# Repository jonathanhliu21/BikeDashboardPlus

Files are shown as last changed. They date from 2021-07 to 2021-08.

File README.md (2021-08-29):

# BikeDashboardPlus

### Go to the [Medium page](https://medium.com/@jonathanhliu21/how-to-make-a-speedometer-tracker-for-a-bike-using-a-raspberry-pi-and-an-arduino-77140be90b9e) for a better installation tutorial! 

- [How to use your Bike Dashboard](docs/pages/usage.md)

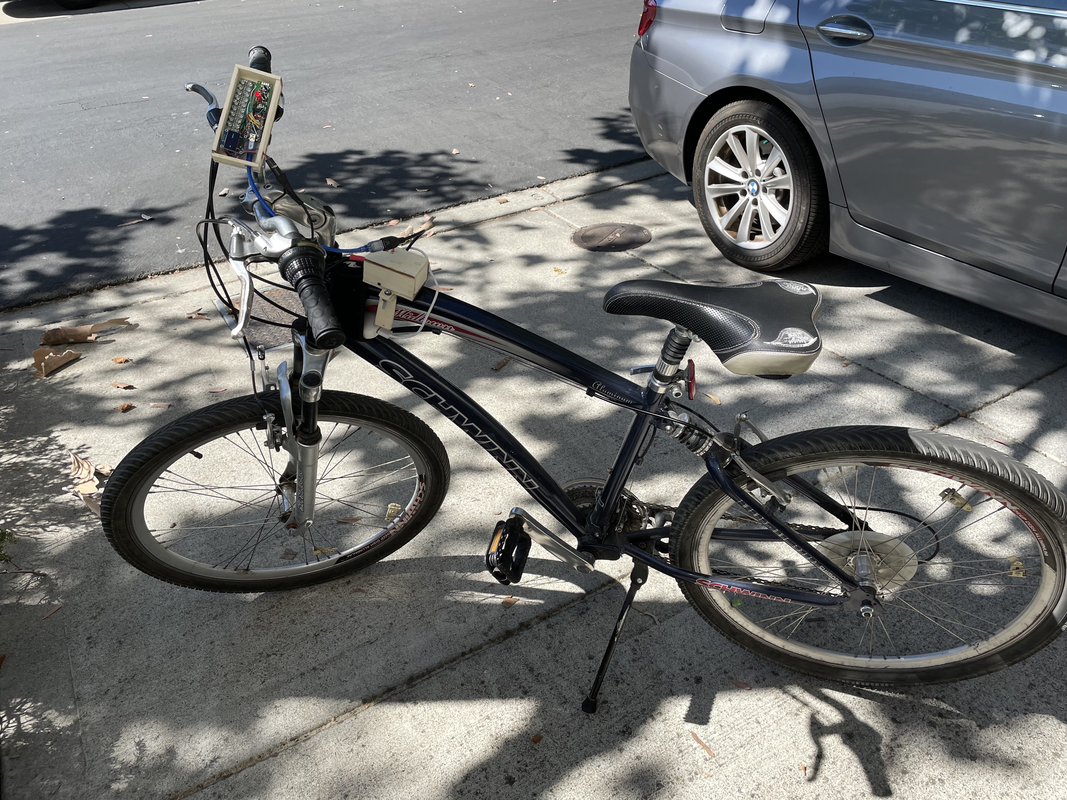
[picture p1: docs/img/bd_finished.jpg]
BD_finished
  

## Description

Over my spring break in April 2021, I made a "Bike Dashboard" ([Project description](https://create.arduino.cc/projecthub/jonathanhliu21/a-dashboard-for-a-bike-unfinished-6dc0cb), [Github Repo](https://github.com/jonyboi396825/BikeDashboard)) using an Arduino Nano, an LCD screen, and a GPS. I made this to make finding out the time while riding a bike safer, and I wanted a safe way to track the route that I biked. I thought that pulling over my bike to check my phone for the time was inconvenient, and checking my phone while biking was dangerous. I was also interested in viewing the speed while biking.

However, That design had many problems. I could not put that many features on it because the Nano did not have much memory. The speed on the LCD updated very slowly. The LCD screen was also very big and captured attention, which may have gotten my bike stolen. Lastly, even though it could track, I had no way of viewing it on a map. Because of these problems, I wanted a new design.

<figure>
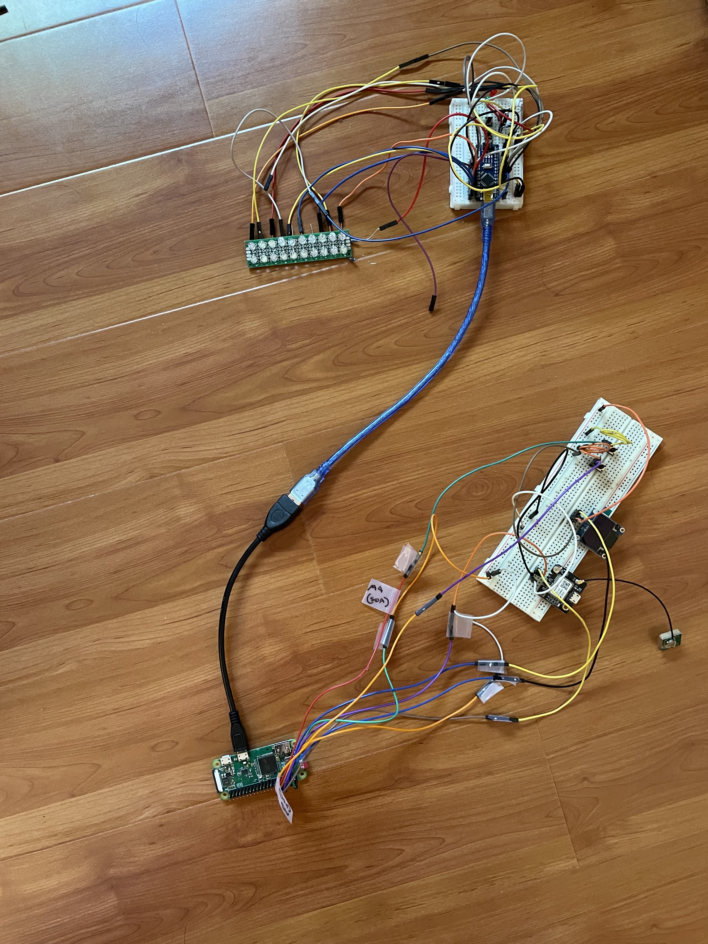
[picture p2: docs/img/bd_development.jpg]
    
    <figcaption>BikeDashboardPlus in development. The breadboard and Raspberry Pi on the bottom would be the central piece, and the breadboard on the top would be the handle piece.</figcaption>
</figure>

## How it works

This new Bike Dashboard features a Raspberry Pi that gets the data from the GPS and puts it onto an OLED. It is connected to the Arduino via USB, and the Arduino controls the buttons for route tracking (start/stop/pause tracking), and a 2x20 LED panel that can currently only display speed by lighting up a certain LED that corresponds to a number.

The OLED displays speed, date and time, how well the GPS is connected (No fix, 2D fix, or 3D fix), and the state of tracking (tracking, paused, or not tracking). 

Additionally, there is another mode called "server mode," where the Raspberry Pi runs a local website. On the website, the user can customize units, time zone, and other features. They can also view their tracked routes on a map. Lastly, if the GPS disconnected or stopped tracking while biking and the user had to restart the tracking, they can combine those two track files into one.

With the Raspberry Pi, I solved the low memory problem and the slowness issue. I was able to get the GPS data in a separate thread so it wouldn't block the program. I tried to make it inconspicuous by using a small OLED and LED panel, but my design still makes the bike capture a lot of attention.

To get a more in-depth understanding of how it works, go [here](docs/pages/usage.md).

## Problems I ran into 

These are some major problems I ran into while working on this project.

| Problem | How I solved it |
|---|---|
| The LED matrix couldn't light up 2 LEDs at once because I wired the circuit wrong. I originally wanted *n* LEDs to light up if I was going at speed *n*. | Instead of resoldering the entire LED matrix, which would have taken a long time, I changed the feature so that only one LED would light up at a time, and that LED would correspond to a certain speed. |
| The light on the LED matrix would be very dim when it lit up. | This was caused by my code not checking if any LEDs in that row were being used, therefore lighting up 2 LEDs back and forth in quick succession, making the LED seem dim. I added an `if` statement that would check if any LEDs were on in that row and turn them off before turning the current one on. |
OSError on OLED: Because I was writing data to the OLED too quickly, after a few minutes, the program would raise an OSError and stop because the data would not be written successfully to the OLED. | I tried experimenting with the amount of delay between writing data to the OLED and seeing how long it would last before raising an OSError. However, I realized I can catch the error and let the user re-begin the OLED, which was a much more reliable solution. |
| The GPS on the bike would take 5 minutes to connect, which was too slow. | I glued the antenna position of the GPS to the top of the central piece instead of the side, so it is pointed directly to the sky. It now takes 1 minute to connect.

Other problems:
- I accidentally soldered the purple LEDs with the white ones on the LED panel because they looked similar (they were both clear).
- For the case, I bought wood too hard to be cut by a knife, so I had to use a saw instead, and it did not cut the wood perfectly. This made it very hard to assemble the case and glue everything together. Thanks to my dad for helping me cut the wood and designing the case and mount.

## Problems that still occur

The bugs are listed below. I will try my best to fix most of them, delete them from this list, and create a new bug-fixing release each time I do so. However, some may take longer than others to fix.

- The shutdown button can be easily pressed so I sometimes accidentally shut down my RPi even when I don't mean to.
- The OLED library I'm using (Adafruit-SSD1306) is deprecated.

### Done
- The track files are in UTC rather than the local time zone

## Upgrade ideas

I will try to implement these enhancements as long as they are not a major change (e.g. a complete rewrite in code, a complete redesign of the mounts and case, needing different parts, or a change in the schematics), or they are not too time-consuming to implement, as I have a very busy schedule. I may not have time to implement all of them. They will be released as features in a minor release.

### Next minor release
- Allow users to separate tracking files after combining them
- If the user chooses to update from the website, then automatically pull from the repository

### Later minor releases
- Track the distance along with coordinates instead of calculating the distance after
- Make the LED panel show more than just speed
- Make a more intuitive configuration page
- Put the Pi in "sleep" mode or alter the OS such that it will boot faster (takes ~2min currently)
- Track speed and time in addition to distance and location

### Next major release
- Remake BOM to include smaller parts and redesign model so everything will be in one small piece attached to the bike

### Done 
- Continue tracking even if disconnected

## Making this project yourself

If you have a Raspberry Pi and a bike, and you are interested in making this project yourself with your Raspberry Pi, then [go here](docs/pages/make_yourself.md).

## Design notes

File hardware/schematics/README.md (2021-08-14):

# Wiring

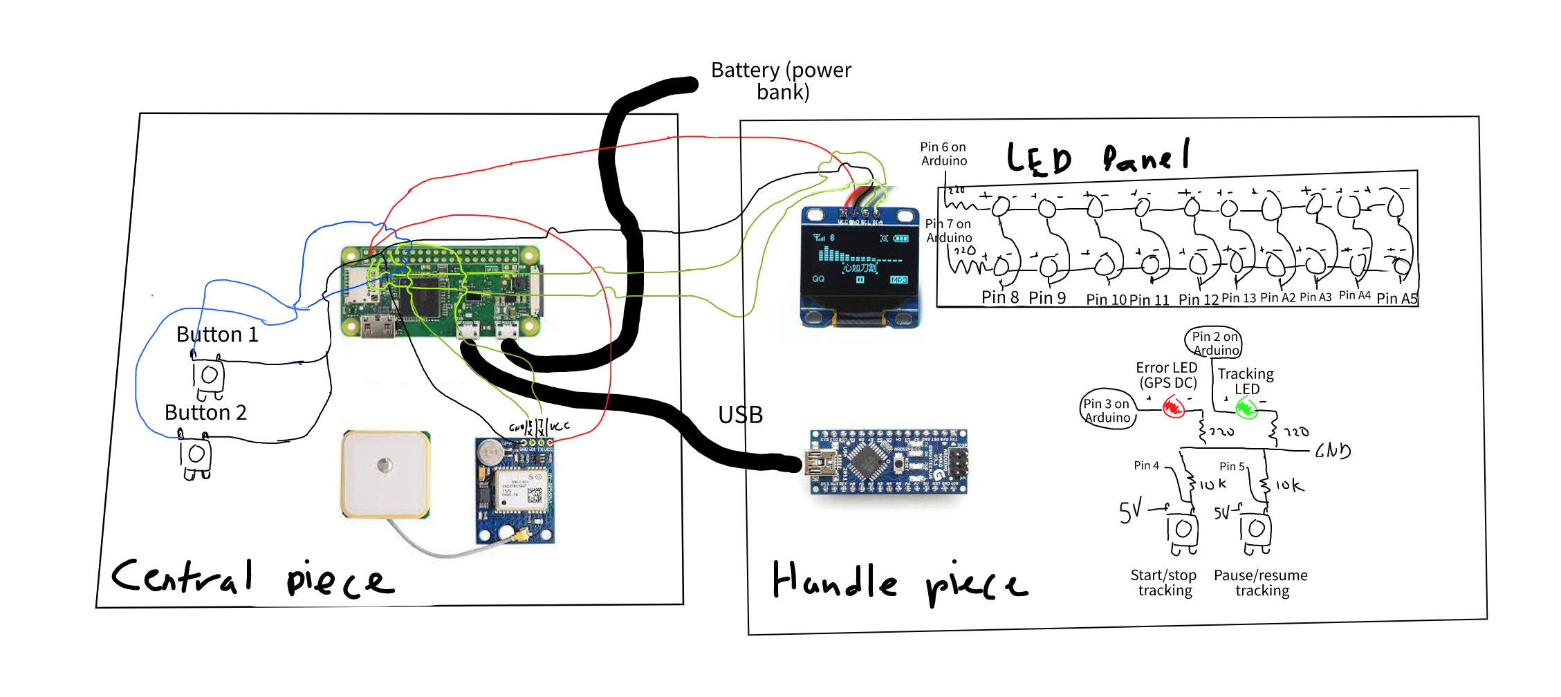
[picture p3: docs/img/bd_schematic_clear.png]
wiring diagram

This is the wiring diagram. Go [here](/docs/img/bd_schematic_clear.png) for a clearer image.

## Raspberry Pi
The left side of the arrow is the pin on the component and the right side is the pin on the Raspberry Pi. For example, `VCC -> 5V` on the GPS would mean to wire `VCC` on the GPS to `5V` on the Raspberry Pi.

1. The GPS
    - `VCC -> 5V`
    - `GND -> GND`
    - `TX -> RX` or `GPIO 15`
    - `RX -> TX` or `GPIO 14`
2. The OLED
    - `VCC -> 5V`
    - `GND -> GND`
    - `SCL -> SCL` or `GPIO 3`
    - `SDA -> SDA` or `GPIO 2`
3. Button 1:
    - Wire one pin to `GPIO 17`
    - Wire the pin across from it to `GND`
4. Button 2:
    - Do the same with button 1 but to `GPIO 18` instead of `17`

## Arduino
1. Error LED: Wire the positive side to `D3` on the Arduino and the negative side to a 220 ohm resistor to ground.
2. Tracking LED: Wire the positive side to `D2` on the Arduino and the negative side to a 220 ohm resistor to ground.
3. Start/stop tracking button: Wire one pin to 5V. Wire the pin across from it to `D4`, and wire the same pin to a 10k ohm resistor to ground.
4. Pause/resume tracking button: Do the same as above but wire it to `D5` instead of `D4`.
5. LED Panel: See picture above. The negative pins of the LEDs get wired to the pins below (pins 8-A5). That is, the wire coming out from the bottom side of an LED in the diagram gets wired to the negative pin of that LED.

Lastly, connect the Raspberry Pi and the Arduino using a USB cable.

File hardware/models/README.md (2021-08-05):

# 3D printing and models

These designs are just an **idea** of how the electronics would be encased and mounted onto the bike. They are designed specifically for my bike and will most likely not work for yours. They should only be used as a **reference** and should **not** be 3D-printed directly. 

The only part I 3D printed from this was a small piece that would hold my Raspberry Pi and my custom-made HAT. The rest I made out of wood. 

[Back](/docs/pages/make_yourself.md)

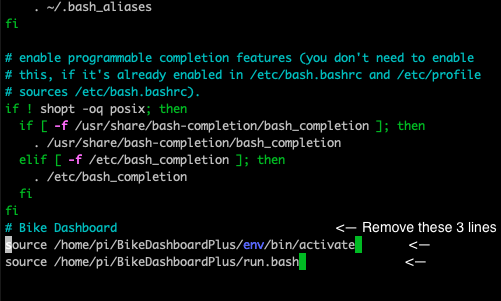
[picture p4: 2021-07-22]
docs/img/bashrc_edit.png

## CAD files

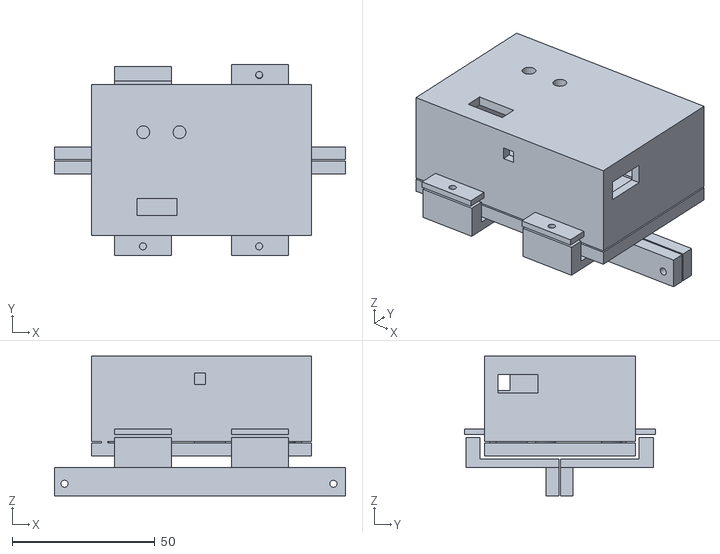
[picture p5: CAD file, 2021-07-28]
hardware/models/center/Central_whole.stl
102.0 x 67.0 x 49.0

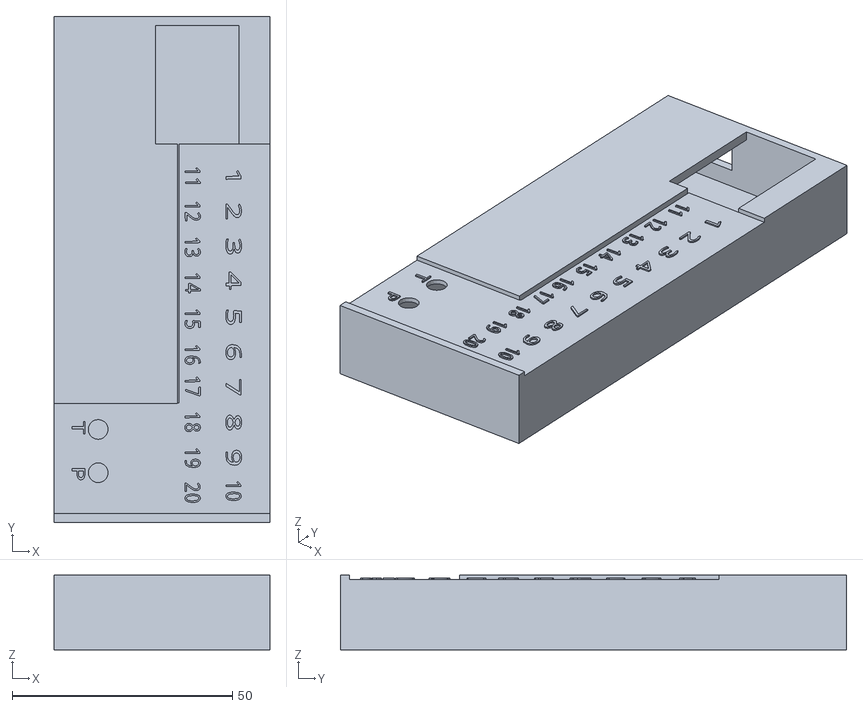
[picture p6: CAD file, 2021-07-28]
hardware/models/handle/Handle_whole.stl
49.0 x 115.0 x 17.0

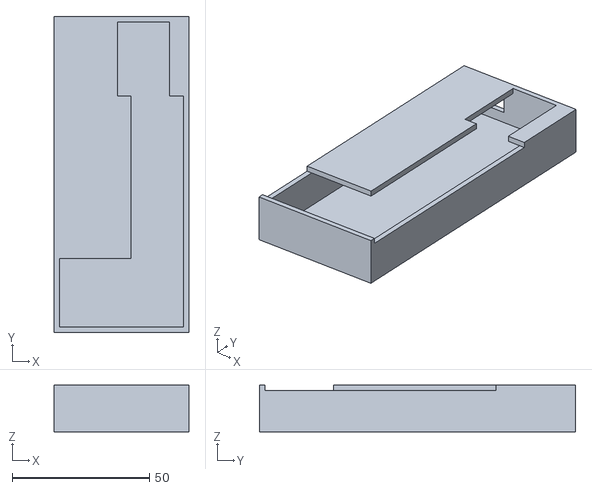
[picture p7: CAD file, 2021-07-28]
hardware/models/handle/Handle_shell.stl
49.0 x 115.0 x 17.0

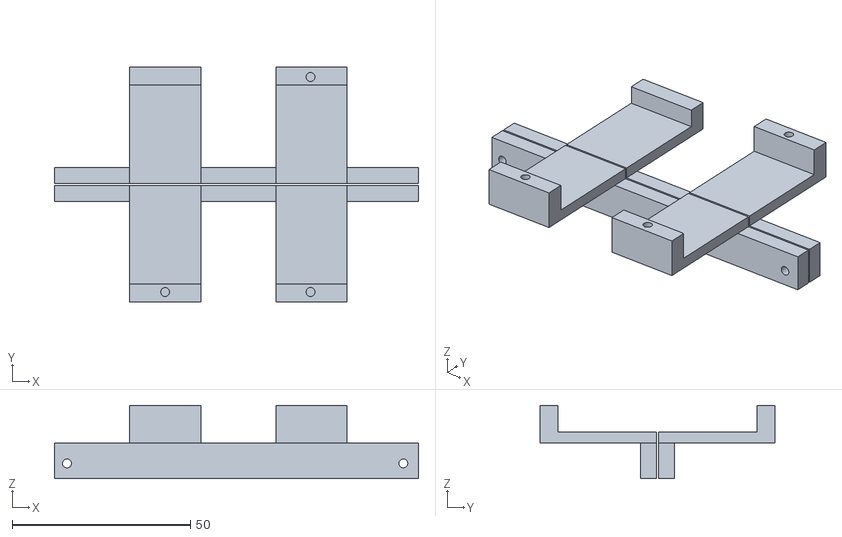
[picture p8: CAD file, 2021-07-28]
hardware/models/center/Central_holder_mount.stl
102.0 x 65.8 x 20.5

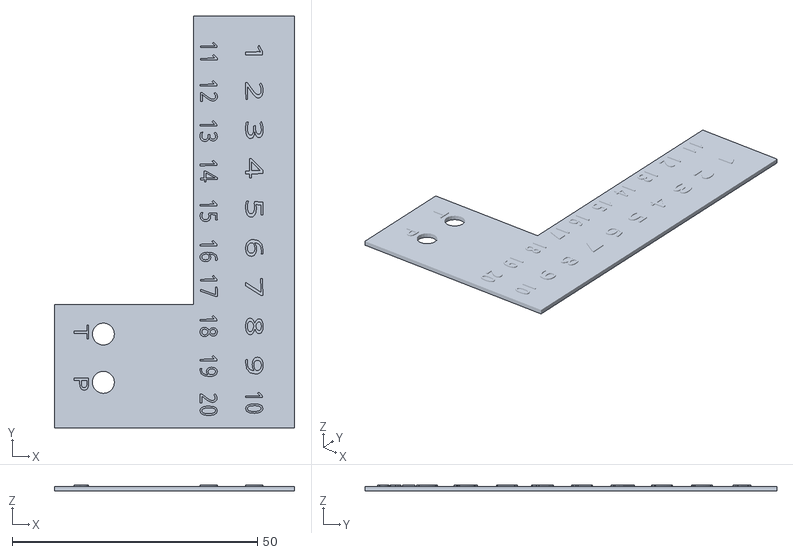
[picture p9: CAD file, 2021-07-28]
hardware/models/handle/LED_piece.stl
49.0 x 84.0 x 1.30

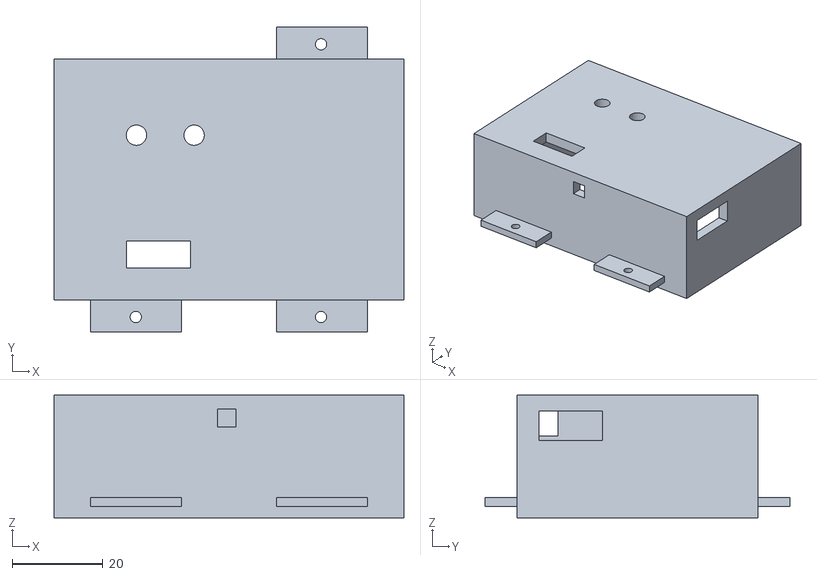
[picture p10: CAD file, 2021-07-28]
hardware/models/center/Central_shell.stl
77.0 x 67.0 x 27.0

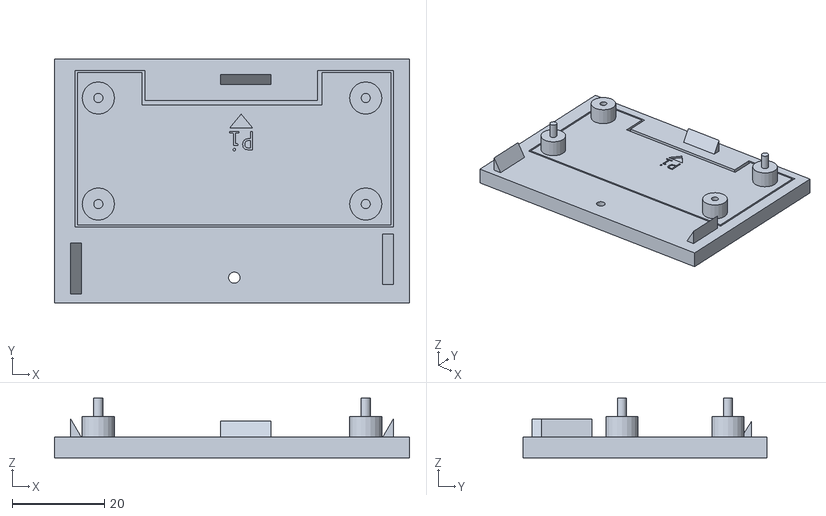
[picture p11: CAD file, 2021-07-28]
hardware/models/center/Central_base.stl
77.0 x 53.0 x 13.0

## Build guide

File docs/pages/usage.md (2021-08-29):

# How to use your Bike Dashboard

[Back to README](/README.md)  
If you have not installed Bike Dashboard, [go here](/docs/pages/make_yourself.md).

There are 2 modes to the Bike Dashboard: Bike mode, and server mode. Bike mode is the mode that you set when you are riding your bike. The OLED display will display time, speed, etc., and you can track your route. Server Mode sets up a server where you can configure your Bike Dashboard and where you can view the maps of your tracked routes.

To turn the Bike Dashboard on, power on your Raspberry Pi and wait 30 seconds to 1 minute to let it boot up. 

To turn it off, press button 2 on the central unit (the one wired to BCM pin 18 on the RPi).

## Bike Mode
The Bike Dashboard automatically goes into Bike Mode when it boots up. 

After displaying some setup text, the OLED will display the things you will see in Bike Mode. This diagram will show what each thing displayed on the OLED represents:

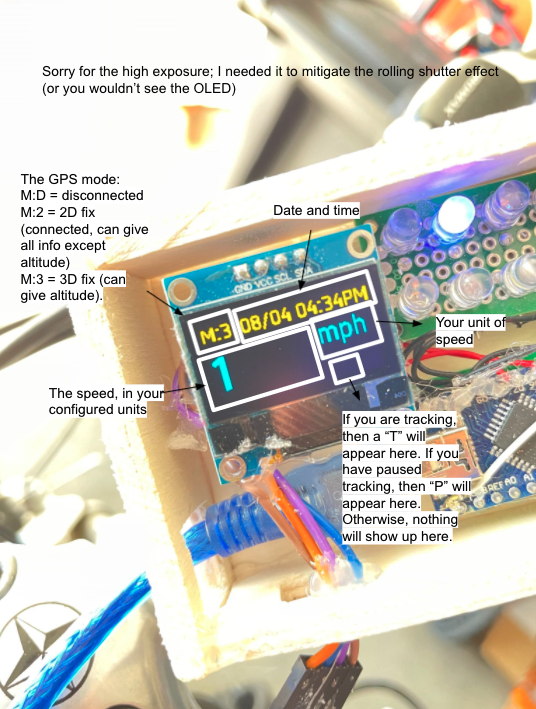
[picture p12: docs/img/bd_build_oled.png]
OLED_tutorial
  

This is how the LEDs on the LED panel are numbered:  
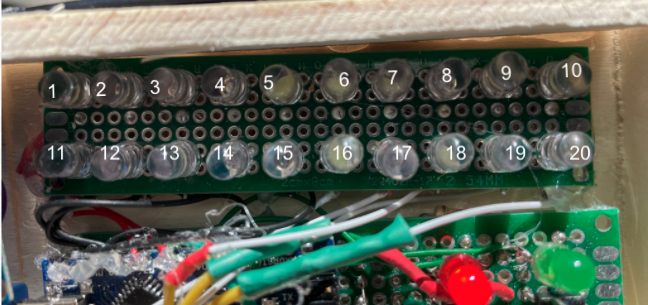
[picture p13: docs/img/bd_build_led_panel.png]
LED_panel_tutorial
  
How it works:
If the configuration "LED" is 0, then LED *n* (on the panel) will light up if you are going *n* mph, km/h, or m/s. If "LED" is set to 1, then LED *n/2* will light up if you are going *n* mph, km/h, or m/s.

To start tracking, press the button wired to pin D4 on the Arduino Nano. The green LED on the Arduino will light up and a "T" will show up on the bottom right of the OLED display to indicate that you are currently tracking. **Note that tracking is not possible if you are disconnected** i.e. the red LED is on or it says "M:D" on the OLED.

Once you have started tracking, it will immediately write to a new track file. If you have started this by accident, don't worry, you can delete this later. 

To pause tracking, press the button wired to pin D5 on the Arduino. Indicators that you have paused are the green LED blinking instead of staying constantly on and the OLED display a "P" on the bottom right corner. To resume, press the same button. 

To end tracking, press the same button as the one you pressed when you started tracking. The green LED will turn off and there should be nothing displayed on the bottom right corner of the OLED. 

### What if my program is always quitting?

If the program is quitting before entering bike mode, and both your OLED and Arduino are connected, it may be that the port to the Arduino in the `port` file is wrong. 

If this happens, `ssh` into your Pi, then [go here](/docs/pages/make_yourself.md) and go under "Installation" to find out which serial port your Arduino is connected to. After that, type in 
```
nano raspberrypi/port
```
then change the port in the file to the new port of the Arduino. Then save and close the file (press ^X, then Y, then enter).

### What if my Arduino or OLED got disconnected?

If your Arduino is disconnected, the OLED should display something beginning with "Oh no!". 

Reconnect your Arduino, wait ~5 seconds, then press button 1 (the one wired to BCM pin 17 on the RPi). If it still displays "Oh no!", then try to disconnect the Arduino and reconnect it again, wait ~15 seconds, then press button 1. If the problem persists, then try to shut it down and start it up again, making sure the Arduino is connected. If it is **still** happening, then go to "What if my program is always quitting?".

If your OLED got disconnected, it should be a blank screen, or the time on the OLED does not match the actual time, and the TX and RX LEDs on the Arduino are not rapidly flashing. 

Try pressing button 1 to restart your OLED. If it is quickly disconnects again, then try unplugging your OLED and plugging it in again. If the problem still persists, then restart your Pi making sure the OLED is connected.

## Server Mode

To get into server mode from bike mode, you need to shut it off and turn it back on again. To do this, press button 2 on the central unit (the one wired to BCM pin 18 on the RPi).

When the "Setup" screen comes on the OLED, press and hold button 1 on the central unit (the one wired to BCM pin 17 on the RPi). When the "Server mode" screen comes on, you are in server mode, and the Raspberry Pi is hosting a website on your network. Note that if there is no internet connection, server mode would fail and it would go into Bike Mode.

Go to the website shown on the OLED. It should be `http://{your.pi.IP}:7123`.

On the home page, you should see this (the version number will be different):   
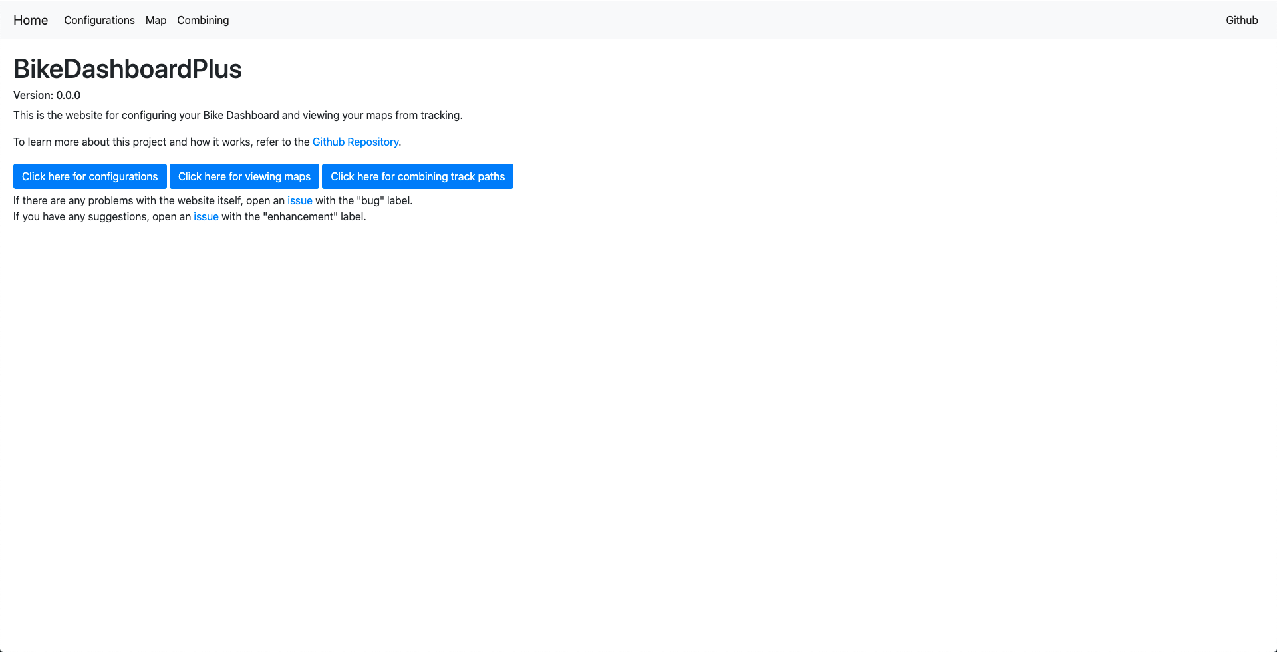
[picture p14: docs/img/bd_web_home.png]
home_page
  
There are 3 options: the configuration page, the map page, and the combining page. I will go through what each one does.

### Configuration
The configuration page should look like this:
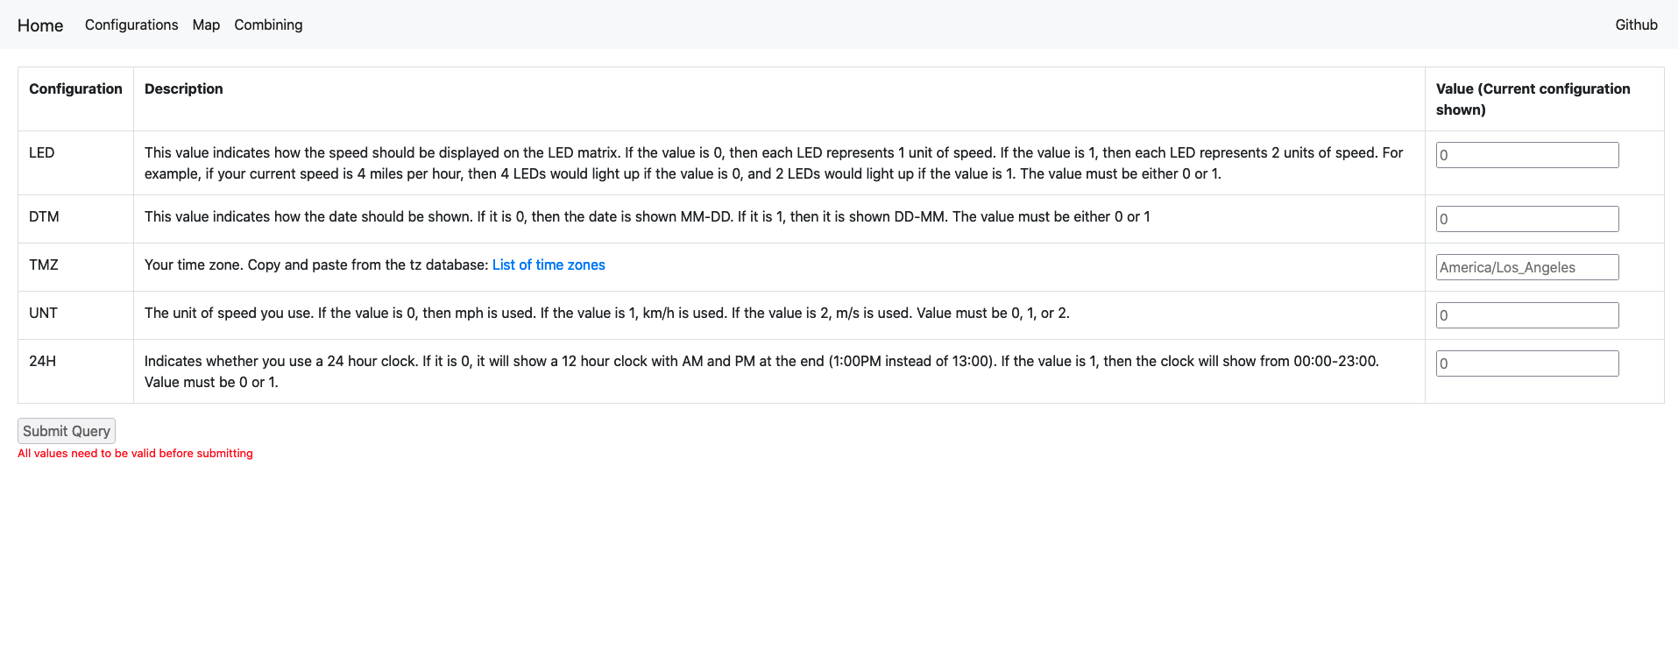
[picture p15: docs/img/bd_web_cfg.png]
cfg_page


There is a table showing all the configurations, what they mean, and what value you have to enter. You have to enter your value into the text box on the right column of the table. The placeholder in each input box shows your current configuration.

For the time zone, you should copy and paste from the list in the link rather than typing it out as it is case sensitive and you have to type it out exactly like it is in the table.

At the end, click submit.

### Map
You should not be able to see anything on the map page if you do not have any track files. If you do, the link name will be something like:
```
Started tracking at: <date> <time> 
```
When you click on it, it should look like this:
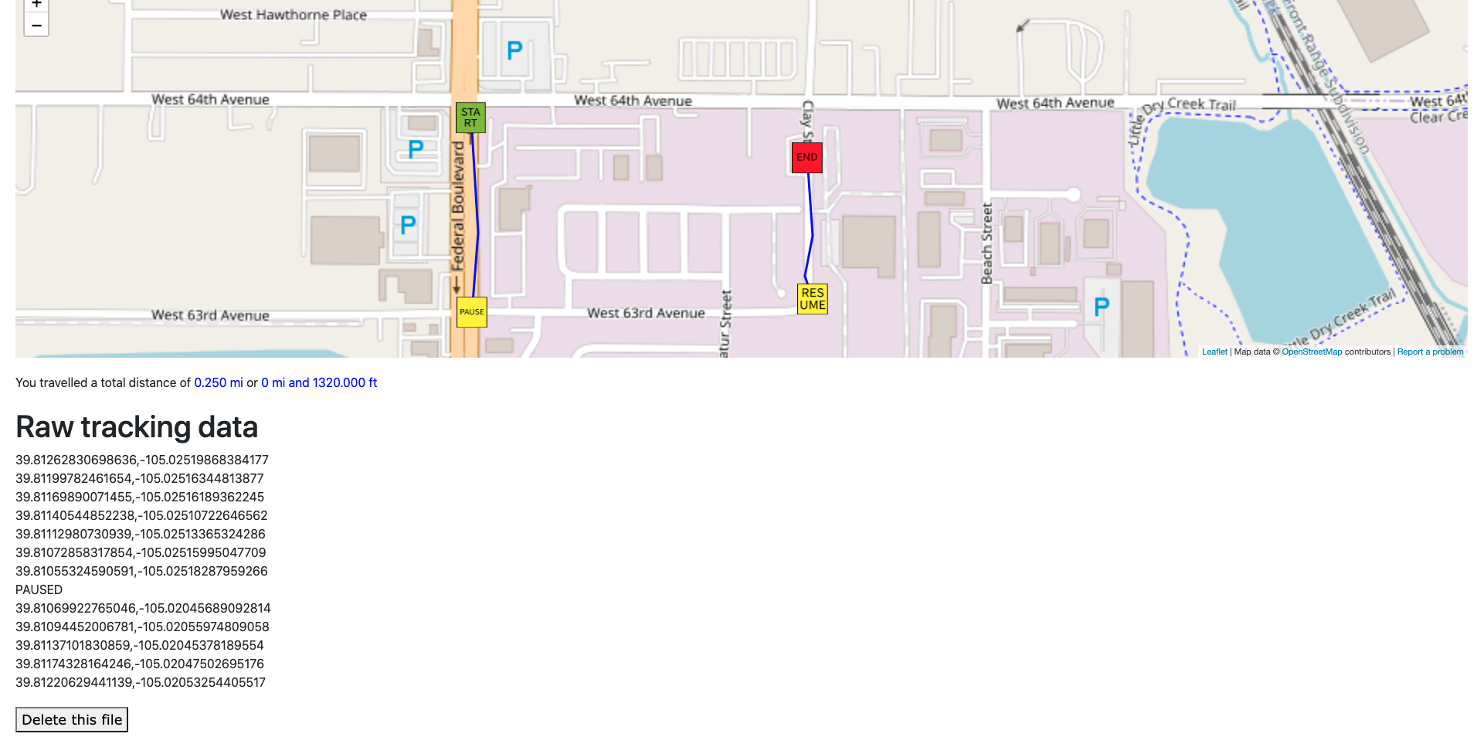
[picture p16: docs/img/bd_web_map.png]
map_page

(Don't worry, I don't live here.)

If you see a message advising you to delete the file, then there was some error writing/reading the tracking file and you should delete it.

The data should not be as precise as shown above as that was copied from Google Maps.

On the map, you should be able to see your route. There are a start marker, an end marker, and multiple pause/resume markers depending on where you paused.

On the bottom of the map, you should see how far you have travelled depending on your "UNT" configuration.
- If "UNT" is 0 (mph), then it shows in miles and feet
- If "UNT" is 1 (km/h) or 2 (m/s), then it shows in kilometers and meters

If you accidentally started tracking and you want to delete the file, press "Delete this file" at the bottom of the page.

### Combining

If your GPS got disconnected whilst tracking, and you had to restart the tracking, leading to 2 or more separate tracking files, you can combine them in the "combining" page. However, on the map, it will indicate that you paused at the end of one tracking file and resumed at the start of the next instead of drawing one continuous line between the two.

**Note that you cannot separate files after combining them.**

Click the checkboxes in the order you want to combine the files. You will see the order of the file numbers below so you can confirm your choices. 

Click submit to combine the files.

### Shutting down

Press the button wired to BCM pin 18 to shut the Pi down.

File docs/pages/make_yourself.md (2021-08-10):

# Making this project yourself
[Back to README](/README.md)  
[How to use the Bike Dashboard](/docs/pages/usage.md)

This page is for people who are interested in making a Bike Dashboard with their own Raspberry Pi. The schematics and designs shown are what work best for me and my bike and may not work for you, so feel free to edit the code, the schematics, and the design for the case and mount. 

## Parts needed

These are the parts you may need to buy to make this project. Depending on how you want to make this project, you can leave out some parts or get other parts. These are just the parts I got.

### Electronics
- [Raspberry Pi Zero W](https://www.amazon.com/Vilros-Raspberry-Starter-Power-Premium/dp/B0748MPQT4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) (This links to a kit)
  - [MicroUSB to USB adapter](https://www.amazon.com/Ksmile%C2%AE-Female-Adapter-SamSung-tablets/dp/B01C6032G0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)
- [Arduino Nano](https://www.amazon.com/REXQualis-Board-ATmega328P-Compatible-Arduino/dp/B07WK4VG58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)
- [Neo-6M GPS module](https://www.amazon.com/Navigation-Positioning-Microcontroller-Compatible-Sensitivity/dp/B084MK8BS2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)
- [128x64 SSD1306 OLED display](https://www.amazon.com/UCTRONICS-SSD1306-Self-Luminous-Display-Raspberry/dp/B072Q2X2LL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)
- [22 LEDs: 20 white, 1 red, 1 green](https://www.amazon.com/eBoot-Pieces-Emitting-Diodes-Assorted/dp/B06XPV4CSH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)
- [Tactile pushbutton switch](https://www.amazon.com/OCR-180PcsTactile-Momentary-Switches-Assortment/dp/B01MRP025V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)
- [Breadboard](https://www.amazon.com/Breadboards-Solderless-Breadboard-Distribution-Connecting/dp/B07DL13RZH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)  (if you don't want to solder, recommended for testing before soldering)
- [Perfboard](https://www.amazon.com/ELEGOO-Prototype-Soldering-Compatible-Arduino/dp/B072Z7Y19F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) or [stripboard](https://www.amazon.com/YUNGUI-Prototype-perfboard-Sording-Electronic/dp/B088GSJM7G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) (for a more permanent build)
- [Jumper wires](https://www.amazon.com/EDGELEC-Breadboard-Optional-Assorted-Multicolored/dp/B07GD2BWPY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)
- [Micro USB cable](https://www.amazon.com/AmazonBasics-Male-Micro-Cable-Black/dp/B0711PVX6Z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) (for power)
- [2 10k ohm resistors and 2 220-330 ohm resistors](https://www.amazon.com/Resistor-Assortment-Kit-Thermistor-Photoresistor/dp/B0792M83JH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)

### Case and mount
The materials depend on how you want to make this project. For example, if you wanted to 3D print the case and the mount to the bike, then you would need a 3D printer and filament. I used:
- [Basswood](https://www.amazon.com/Basswood-Sheets-Unfinished-Plywood-Crafts/dp/B08VN3HXDT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) (I got a much harder and thicker type of wood. This wood should be easily cuttable with a razor blade or a x-acto knife.)
- [X-acto knife](https://www.amazon.com/X-Acto-XZ3601-X-ACTO-Knife-Safety/dp/B005KRSWM6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)
- [Hand saw](https://www.amazon.com/CRAFTSMAN-Hand-12-Inch-Hacksaw-CMHT20138/dp/B07R92S9YZ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) 
- [Hot glue, hot glue gun](https://www.amazon.com/Gluerious-Sticks-Crafts-School-Repairs/dp/B08FTHWC94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)
- [Gorilla glue](https://www.amazon.com/Gorilla-Original-Waterproof-Polyurethane-Bottle/dp/B0000223UV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)

## Schematic
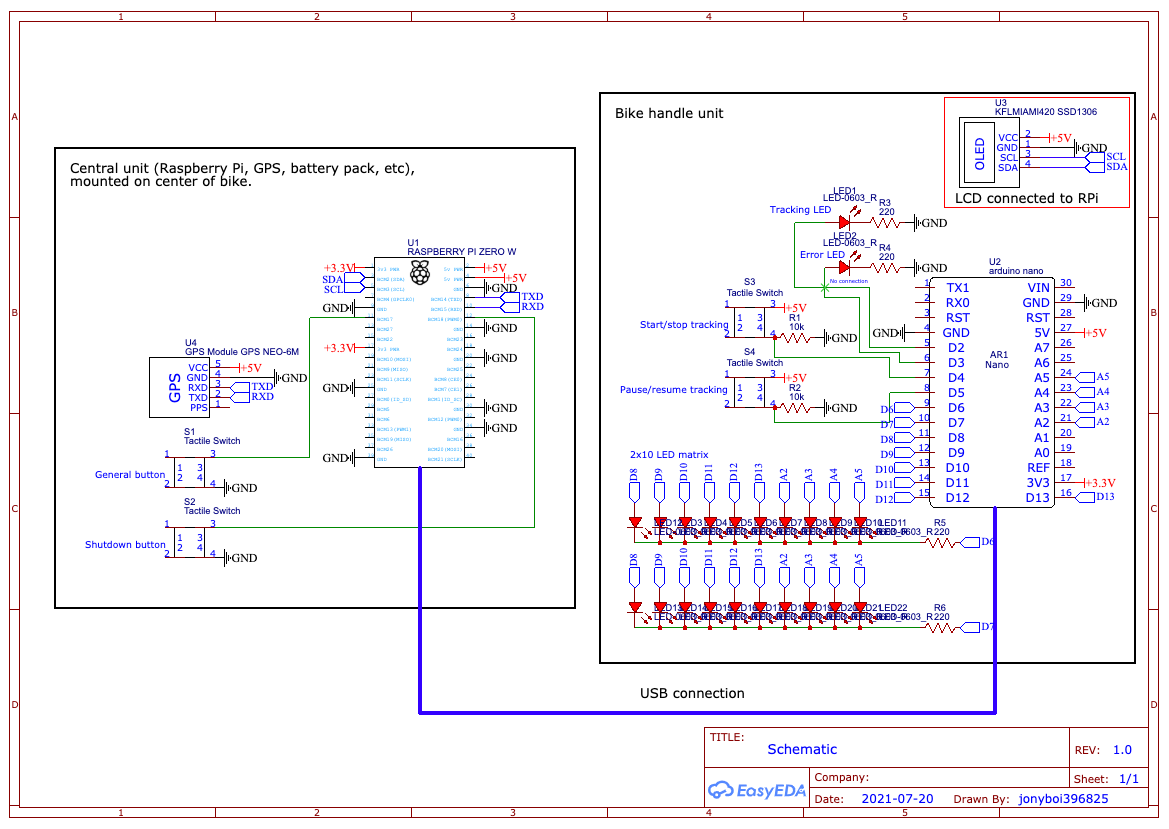
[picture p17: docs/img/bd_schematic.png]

Actual schematic

more intuitive schematic
A more intuitive schematic

If you do not feel like soldering, you can use a breadboard.

I did not design a PCB for this schematic. Instead, I soldered all of these components onto a prototype PCB, which was hard and time-consuming. I may design a custom PCB later. Also, soldering the LED panel is optional as all information displayed there will be displayed on the OLED.

## 3D Printing

More information on 3D Printing and the case/mount design can be found [here](https://github.com/jonyboi396825/BikeDashboardPlus/tree/master/hardware/models).

## Installation

There will be two steps during installation: configuring your Pi so the software will work, and installing the software. However, before that:

If you haven't installed the Raspberry Pi OS, follow the instructions below. Make sure to install "Raspberry Pi OS (32 bit)" and not any other OS as they might not come with Python, cURL, or git.
- [Setting up the Raspberry Pi](https://projects.raspberrypi.org/en/projects/raspberry-pi-setting-up)
- [Setting up the Raspberry Pi headless](https://www.raspberrypi.org/documentation/configuration/wireless/headless.md)

- Python installation if you do not have it installed
  ```
  sudo apt update
  sudo apt install python3 idle3
  ```

- cURL installation if you do not have it installed:
  ```
  sudo apt update
  sudo apt install curl
  ```

- Git installation if you do not have it installed
  ```
  sudo apt update
  sudo apt install git
  ```

### Configuring

Configuring git:
1. Type in `git config --global user.name "Your name"`
2. Type in `git config --global user.email "your@email.com"`  
Replace `"Your name"` and `"your@email.com"` with your actual name and your actual email.

Configuring the pins: 
1. Type in `sudo raspi-config`
2. Go to "Interface options" and select `I2C`, then select Yes.
3. Return to "Interface options" and select `Serial Port`. When it asks `Would you like a login shell to be accessible over serial?`, select No. It will then ask, `Would you like the serial port hardware to be enabled?`, and select Yes.
4. Click Finish.
5. Reboot the Raspberry Pi: `sudo reboot`

### Installing

1. To install BikeDashboard Plus, first run this command: 
    ```
    curl -sO https://raw.githubusercontent.com/jonyboi396825/BikeDashboardPlus/master/install.bash
    ```

    After running this, you will have to figure out the serial port of your Arduino. Type `ls -l /dev` to see all serial ports. The port for the Arduino should be `ttyUSB*` or `ttyACM*`. The best way to check which port the Arduino is located on is to plug in the Arduino, take note of the ports that are `ttyUSB*` or `ttyACM*`, then unplug the Arduino, and see which of those ports disappeared. That port would be the Arduino.

    After getting the path to the serial port (ex `/dev/ttyUSB0` or `/dev/ttyACM0`), type this command in:
    
    ```
    bash install.bash /dev/port
    ```
    Replace `/dev/port` with the actual path to the serial port. The installation process should take around 1-2 minutes on a Raspberry Pi 4 and around 8-10 minutes on a Raspberry Pi Zero.

2. Make a backup of /etc/rc.local: `sudo cp /etc/rc.local /etc/rc_backup.local`
3. Edit /etc/rc.local
- Type `sudo nano /etc/rc.local`
- Scroll down. Type in `su pi -c "bash /path/to/BikeDashboardPlus/run.bash" &` **before the** `exit 0`. You can find out the path by typing `cat ~/BikeDashboardPlus.txt`. **Make sure to add the ampersand or the Pi will not boot.** This line will make the Raspberry Pi run the program when it boots. The `su pi -c` runs the program as the `pi` user so you would be able to access the files in the program later.
- Save and exit: Press ^X (Control-X), then Y, then enter. 

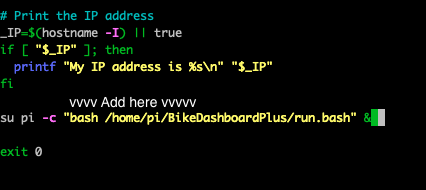
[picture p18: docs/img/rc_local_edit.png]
    
  *Don't* add the `vvvv Add here vvvv`. That is just to show where to add the line.

4. Reboot the Pi: `sudo reboot`

From now on, the program should run after you boot up your Raspberry Pi.

## Disabling
This prevents the program from running whenever you start up your Raspberry Pi.

1. Type `sudo nano /etc/rc.local`
2. Delete the line that you added when installing (shown in the image above).
3. Save and exit: Press ^X (Control-X), then Y, then enter.
4. Reboot the Pi: `sudo reboot`.

To re-enable it, just type that line back into `/etc/rc.local` at the same place.
    
## Uninstalling

1. Disable the program (See "Disabling")
2. `cd` into the directory you installed BikeDashboardPlus in.
- You can check by typing `cat ~/BikeDashboardPlus.txt`
3. Type `rm -rf BikeDashboardPlus` to delete the folder and all of its contents.
4. Type `rm ~/BikeDashboardPlus.txt`
5. Reboot the Pi: `sudo reboot`

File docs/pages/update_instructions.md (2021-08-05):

# Updating your Bike Dashboard

By updating, you are syncing your local main branch with the Github master branch.

1. `ssh` into your pi: 
    ```
    ssh pi@your.pi.IP
    ```

2. `cd` into your BikeDashboardPlus directory. You can check the Bike Dashboard directory by typing `cat ~/BikeDashboardPlus.txt` 

3. Run this command (it syncs the code on the master branch on Github with the code on your local Pi):
    ```
    git pull --rebase origin master
    ```
    This will not delete your tracking or error files because they were put inside `.gitignore` when installing.   
    Note that this command will not work if you have uncommitted changes.

4. Reboot your Pi:
    ```
    sudo reboot
    ```

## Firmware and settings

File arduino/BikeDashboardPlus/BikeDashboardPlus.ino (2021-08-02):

/*
MIT License

Copyright (c) 2021 jonyboi396825

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
THE SOFTWARE IS PROVIDED "AS IS", WITHOUT WARRANTY OF ANY KIND, EXPRESS OR
IMPLIED, INCLUDING BUT NOT LIMITED TO THE WARRANTIES OF MERCHANTABILITY,
FITNESS FOR A PARTICULAR PURPOSE AND NONINFRINGEMENT. IN NO EVENT SHALL THE
AUTHORS OR COPYRIGHT HOLDERS BE LIABLE FOR ANY CLAIM, DAMAGES OR OTHER
LIABILITY, WHETHER IN AN ACTION OF CONTRACT, TORT OR OTHERWISE, ARISING FROM,
OUT OF OR IN CONNECTION WITH THE SOFTWARE OR THE USE OR OTHER DEALINGS IN THE
SOFTWARE.
*/

#define LED1 2
#define LED2 3
#define BUTTON1 4
#define BUTTON2 5
#define INTERVAL 500

#define ROWS 2
#define COLS 10

#include <ArduinoJson.h>
#include <Wire.h>

typedef unsigned long long ull;

// LED display
const int row[ROWS] = {6, 7};
const int col[COLS] = {8, 9, 10, 11, 12, 13, A2, A3, A4, A5};
bool disp[ROWS][COLS];

// serial communication with RPi
StaticJsonDocument<128> send_doc;
StaticJsonDocument<256> receive_doc;

// Cfg
uint8_t led, dtm, bc1, bc2, bc3;

// states of buttons (cur state, prev state)
bool s1, s2, ps1, ps2; 
uint8_t unit; // 0 = mph, 1 = km/h, 2 = m/s

// blinking the LED
ull blinkPrevMillis = 0;
bool states[] = {0, 0, 0, 0};

void setup(void){
    Serial.begin(115200);

    // get configurations from RPi
    send_doc["REQ"] = 0;
    send_doc["BUTTON1"] = false;
    send_doc["BUTTON2"] = false;

    String buf;
    serializeJson(send_doc, buf);
    Serial.println(buf);
    
    while (not Serial.available());
    if (Serial.available()){
        buf = Serial.readStringUntil('\n'); 
    }
    deserializeJson(receive_doc, buf);

    if (receive_doc.containsKey("LED") and receive_doc.containsKey("DTM")){
        led = receive_doc["LED"];
        dtm = receive_doc["DTM"];
        unit = receive_doc["UNT"];
    }

    // pins 
    pinMode(LED1, OUTPUT);
    pinMode(LED2, OUTPUT);
    
    pinMode(BUTTON1, INPUT);
    pinMode(BUTTON2, INPUT);

    for (auto i: row) pinMode(i, OUTPUT);
    for (auto i: col){
        pinMode(i, OUTPUT);
        digitalWrite(i, HIGH);
    }
}

void loop(void){
    send_doc["REQ"] = 1;

    // get states 
    s1 = digitalRead(BUTTON1);
    s2 = digitalRead(BUTTON2);
    
    // on release
    if (not s1 and ps1) send_doc["BUTTON1"] = true;
    if (not s2 and ps2) send_doc["BUTTON2"] = true;

    // get data from serial and send states to serial
    String buf = Serial.readStringUntil('\n');
    deserializeJson(receive_doc, buf);

    buf = "";
    serializeJson(send_doc, buf);
    
    Serial.println(buf);
    delay(0.01);

    if (receive_doc.containsKey("GPS")){
        // B1RCV/B2RCV alg
        if (receive_doc["B1RCV"]) send_doc["BUTTON1"] = false;
        if (receive_doc["B2RCV"]) send_doc["BUTTON2"] = false;

        // arrays in the JSON doc
        JsonArray gpsArr = receive_doc["GPS"].as<JsonArray>();
        JsonArray ledArr = receive_doc["LED"].as<JsonArray>();

        // String test = "";
        // serializeJson(ledArr, test);
        // Serial.println(test);

        // toggle LEDs
        if (ledArr[0] == 0){
            digitalWrite(LED1, LOW);
        }
        else if (ledArr[0] == 1){
            toggleLED(LED1);
        }
        else if (ledArr[0] == 2){
            digitalWrite(LED1, HIGH);
        }

        if (ledArr[1] == 0){
            digitalWrite(LED2, LOW);
        }
        else if (ledArr[1] == 1){
            toggleLED(LED2);
        }
        else if (ledArr[1] == 2){
            digitalWrite(LED2, HIGH);
        }

        // convert units
        gpsArr[2] = convToUnit(gpsArr[2]);

        // 1 LED = 2 units of speed if config[LED] is 1, so we can divide by 2
        if (led == 1) gpsArr[2] = (gpsArr[2].as<int>())/2;
        
        // display speed on LED panel according to configuration
        if (gpsArr[2] <= 0) clearScrn();
        else if (gpsArr[2] >= 20) {
            clearScrn();
            numToArr(19, HIGH);
        }
        else {
            clearScrn();
            numToArr(round(gpsArr[2].as<double>())-1, HIGH); // 1mph should be LED0
        }
        modDisp(); // put arr to LED
    } else{
        // turn everything off

        digitalWrite(LED1, LOW);
        digitalWrite(LED2, LOW);
        
        clearScrn();
        modDisp();
    }

    // prev states
    ps1 = s1;
    ps2 = s2;
}

// modifies arr to value (HIGH or LOW) based on LED num
void numToArr(int lnum, bool val){
    if (lnum < 0 or lnum > 19) return;

    if (lnum >= 0 and lnum < 10) disp[0][lnum] = val;
    if (lnum >= 10 and lnum < 20) disp[1][lnum-10] = val;
}

// sets all values to LOW
void clearScrn(void){
    for (int r = 0; r < ROWS; r++){
        for (int c = 0; c < COLS; c++){
            disp[r][c] = LOW;  
        }  
    }  
}

// sets all values to HIGH
void allScrn(void){
    for (int r = 0; r < ROWS; r++){
        for (int c = 0; c < COLS; c++){
            disp[r][c] = HIGH;  
        }  
    }  
}

// modifies display based on disp[][] matrix
void modDisp(void){ // HIGH = on, LOW = off
/*    2x10 LED matrix
//
//        8  9  10 11 12 13 A2 A3 A4 A5    
//      |-------------------------------|
//  6 R |  0  1  2  3  4  5  6  7  8  9 |
//      |                               |
//  7 R | 10 11 12 13 14 15 16 17 18 19 |
//      |-------------------------------|
//    R = 220 ohms
//
//    Numbers represent LEDs and 
//    the numbers on the side represent pins
//    R represents resistors
*/
    for (int r = 0; r < ROWS; r++){
        bool hasOn = false;
        for (int c = 0; c < COLS; c++){
            hasOn = (hasOn || disp[r][c]);
        }

        digitalWrite(row[r], hasOn);
        for (int c = 0; c < COLS && hasOn; c++){
            digitalWrite(col[c], not disp[r][c]);
        }
    }
}

int convToUnit(int sp){
    /*
    Assumes that default is given in mph because the
    default speed for the Neo6M is mph
    */

    if (unit == 0) return sp; // mph
    else if (unit == 1) return ((int) (sp/1.0)*1.609); // km/h
    else return ((int) (sp/1.0)/2.237); // mph
}

void toggleLED(int led){
    if (millis() - blinkPrevMillis >= INTERVAL){
        blinkPrevMillis = millis();

        if (states[led] == LOW){
            states[led] = HIGH;
        } else{
            states[led] = LOW;
        }
    }

    digitalWrite(led, states[led]);
}

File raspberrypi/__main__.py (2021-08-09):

# MIT License

# Copyright (c) 2021 jonyboi396825

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
import datetime
import subprocess
import threading
import time

import Adafruit_SSD1306
import requests
import serial
from gpiozero import Button
from PIL import Image, ImageDraw, ImageFont

BUTTON_PIN = 17
BUTTON_SH_PIN = 18
CMD_BIKE_MODE = "python3 raspberrypi/bike_mode.py 2>> errors.txt && printf \"Happened at $(date)\\n\\n\" >> errors.txt;"
CMD_SERVER_MODE = "python3 raspberrypi/server_mode.py 2>> errors.txt && printf \"Happened at $(date)\\n\\n\" >> errors.txt;"

class InitiationError(Exception):
    """
    This error is raised if could not initialize OLED or Arduino.
    """
    def __init__(self, code, *args, **kwargs):
        self.code = code
        self.which = kwargs["which"]
        self.msg = f"{self.which} could not be initialized."

        super().__init__(self.msg)

    def __repr__(self):
        return f"{self.msg} Exiting with code {self.code}."

def handle_bike_mode() -> None:
    global display, img, draw, font, b

    draw.rectangle((0, 0, 128, 128), fill=0)
    draw.text((0, 0), "Restart to switch mode ", fill=255, font=font)
    draw.text((0, 16), "No press detected \nEntering bike mode", fill=255, font=font)
    display.image(img)
    display.display()
    time.sleep(2)

    while True:
        # using subprocess instead of import so an error would not exit out of the whole program and the process would be easier to kill
        subprocess.call(CMD_BIKE_MODE.split())

        # if exits out here, means that OS error happened/Arduino disc or OLED disc
        try:
            # put in try because OLED may be disconnected
            draw.rectangle((0, 0, 128, 128), fill=0)
            draw.text((0, 0), "Oh no!", fill=255, font=font)
            draw.text((0, 16), "OLED or Arduino \ndisconnected. Reconn., \npress B1 try again.", fill=255, font=font)
            display.image(img)
            display.display()
            time.sleep(1)

        except:
            pass

        # let user press button after reconnected and then try again
        b.wait_for_press()
        time.sleep(2) # wait 2 seconds just in case of conflict with writing to OLED

def handle_server_mode() -> None:
    global display, img, draw, font

    # checks for internet connection in order to enter server mode
    try:
        requests.get("https://google.com")

        # display the pi IP as website
        website_name = _get_pi_ip()

        draw.rectangle((0, 0, 128, 128), fill=0)
        draw.text((0, 0), "Restart to switch mode ", fill=255, font=font)
        draw.text((0, 16), f"In server mode \nVisit website: \n{website_name}:7123", fill=255, font=font)
        display.image(img)
        display.display()
        time.sleep(1)

        # using subprocess instead of import so an error would not exit out of the whole program and the process would be easier to kill
        subprocess.call(CMD_SERVER_MODE.split())
    except requests.exceptions.ConnectionError:
        # enter bike mode if no internet connection

        draw.rectangle((0, 0, 128, 128), fill=0)
        draw.text((0, 0), "No connection", fill=255, font=font)
        draw.text((0, 16), "Going into \nbike mode", fill=255, font=font)
        display.image(img)
        display.display()
        time.sleep(1)

        handle_bike_mode()
        return

def shutdown_button() -> None:
    global display, img, draw, font

    # wait 30 seconds so the button wouldn't interfere with any of the setup stuff
    time.sleep(30)

    # shuts down pi when this is pressed

    sh_b = Button(BUTTON_SH_PIN)
    sh_b.wait_for_press()

    # stop all sub programs
    STOP_CMD_BK = "pkill -f raspberrypi/bike_mode.py"
    STOP_CMD_SV = "pkill -f raspberrypi/server_mode.py"
    subprocess.call(STOP_CMD_BK.split())
    subprocess.call(STOP_CMD_SV.split())

    time.sleep(1)

    draw.rectangle((0, 0, 128, 128), fill=0)
    draw.text((0, 0), "Powering off", fill=255, font=font)
    draw.text((0, 16), "Wait for green LED \non RPi to turn off \nbefore switching off.", fill=255, font=font)
    display.image(img)
    display.display()
    time.sleep(1)

    # power off
    POWER_OFF_CMD = "sudo shutdown -h now"
    subprocess.call(POWER_OFF_CMD.split())

def _check_components() -> bool:
    """
    Checks that all components are connected properly before starting the program.
    """

    try:
        # check display
        display = Adafruit_SSD1306.SSD1306_128_64(rst=None)
        display.begin()

        # check serial port
        pt_f = open("raspberrypi/port", 'r')
        pt = pt_f.read().strip()
        ser = serial.Serial(pt, 115200)
        ser.flush()
        pt_f.close()

    except OSError as e:
        if (e.errno == 2):
            print("Serial port could not be opened.")
            return "Serial port"
        elif (e.errno == 121):
            print("OLED could not be initialized.")
            return "OLED"
        return "Something"

    return ""

def _get_pi_ip() -> str:
    s_p = subprocess.Popen("hostname -I".split(), stdout=subprocess.PIPE, stderr=subprocess.PIPE)
    output, err = s_p.communicate()
    return output.decode("utf-8").rstrip()
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

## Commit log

2021-07-16 stage 5.5: added internet checking
2021-07-16 fixed gps time format issue
    [bike_mode.py]
2021-07-17 Stage 6: Added tracking map
2021-07-18 Stage 7: Safe power off
2021-07-20 Stage 8: Installer
2021-07-20 Changes to install.bash
    Copies install.bash to install_backup.bash only if detected operating system is a Raspberry Pi. Installs needed Arduino libraries such as ArduinoJSON from Arduino-CLI.
2021-07-22 Un-daemonized shutdown_button()
    Putting shutdown_button() in a daemon thread made the shutdown process exit before it could actually run the shutdown command because when the server mode subprocess is killed, it exits out of the ma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
2021-07-28 add stl files
    [Central_base.stl, Central_holder_mount.stl, Central_shell.stl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]
2021-07-28 added schematic to hardware
2021-07-29 removed back button from combine
2021-07-29 better valid-checking for track map pages
2021-07-30 Revert "added update"
    This reverts commit b677b4b1beb5e1c36036602056a2a4250043281c.
    [server_mode.py]
2021-08-02 specify what button to press
2021-08-02 add error checking in py subprograms
    [__main__.py]
2021-08-02 convert unit when sending to arduino
2021-08-06 custom error msg, cleaned up code
    [__main__.py]
2021-08-06 what if arduino port is wrong
2021-08-08 exit program when OLED disconnects
    this lets the user reconnect the OLED by restarting bike_mode by pressing button
2021-08-09 closed files, print oled err
    now prints error to stderr whenever oled gets disconnected
    [bike_mode.py]
2021-08-09 added arduino oled disc. instructions
2021-08-09 fixed track on startup
    checked if disconnected before assigning wastracking to true to prevent start on startup
    [bike_mode.py]
2021-08-09 Check for error files
    [server_mode.py]
2021-08-10 update BOM
2021-08-10 added more intuitive schematic
2021-08-10 custom pcb later
2021-08-14 added wiring instructions
2021-08-15 added no track files msg
2021-08-15 made track file name local tmz
2021-08-15 fixed tmz conversion, can pause again
    [bike_mode.py]
2021-08-29 Shows current configurations
